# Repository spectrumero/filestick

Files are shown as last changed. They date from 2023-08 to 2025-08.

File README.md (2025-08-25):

# FileStick

This is still a very early work in progress.

This project implements an Econet fileserver "onna stick". Acorn had
the FileStore, so this is kind of a play on words on the FileStore.
The system is built on a Lattice UltraPlus 5K FPGA, which includes
128kbyte of static RAM on the chip, as well as a number of dual ported
blockrams, which makes it ideal for a small system project.

The prototype board is based on the UPduino 3.1 board.
See: https://tinyvision.ai/products/upduino-v3-1

The version 1 board contains the econet front end, the up5k FPGA,
an SD card slot, flash memory and a USB interface, implemented with
an FTDI USB UART.

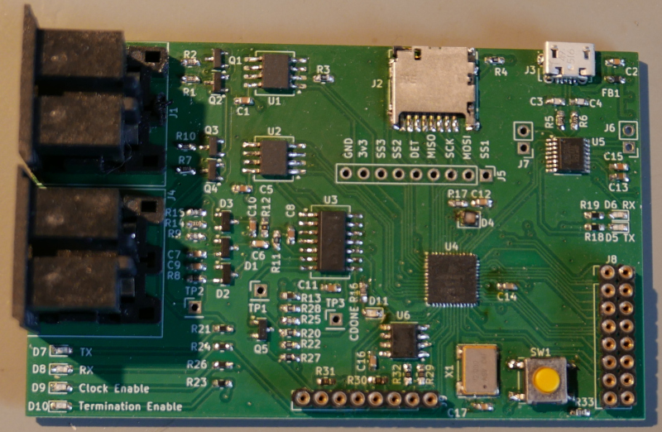
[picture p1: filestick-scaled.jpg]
V1 board


The system consists of a RISC-V core (modified FemtoRV core supporting
some extra CSRs, the ecall instruction to handle system calls, ebreak
and some limited illegal instruction trapping). The core is an rv32imc
(RISC-V 32 bit with the multiply/divide and compressed instructions
extensions).

## Features

* USB powered, < 500mA
* Simple RISC-V implementation and early microcomputer style operating
system. System functions via `ecall` interface.
* Fully buffered econet implementation, with econet exposed via standard
open/read/write/close/ioctl operations.
* Switchable econet clock generation and termination, so that you don't
need a separate clock and terminators for a small Econet.
* Programmable timers.
* USB serial interface with hardware FIFO and hardware CTS/RTS flow control.
Has an interactive mode for use as the system console and raw mode for
transferring files over USB etc.
* FAT support using FatFS for both microSD and built-in flash.
* RGB LED, useful for showing system activity.
* C / C++ programming made easy with newlib and GCC riscv cross compiler,
and a lightweight library and specs file for system-specifics.

## Project structure

* hardware: Contains the Verilog source code. Requires a recent version
of yosys, nextpnr, and the icestorm tools. (Debian users will need to
build these from source, as Debian is still on the old arachnepnr).

* system: Contains the operating system. This isn't a multiuser/
multitasking operating system, it's an OS in the vein of a classic
home micro's operating system. It does provide a number of system
calls using the Linux rv32 syscall numbers. Remember there is no
virtual memory on this very small system, however, some simple memory
protection is planned so that user programs can't accidentally
overwrite kernel memory or device address space.

* lib: The filestick library. This is required for most userspace programs
as at the very least it provides the sbrk implementation needed to properly
support libc's malloc.

## Toolchain

The xPack GNU RISC-V embedded GCC project is used to build all source
code. xPack provides ready-to-run toolchains for many platforms including
Linux, Windows and MacOS. Other GCC toolchains will probably work, but xPack
is likely the easiest/most convenient to use.

The xPack toolchain includes newlib (the libc).

See their releases here: 
https://github.com/xpack-dev-tools/riscv-none-elf-gcc-xpack/releases

The build system uses cmake. If you're running Linux, your distro almost
certainly has cmake. Otherwise see: https://cmake.org/

## Building

To build the gateware, you will need yosys, nextpnr and icestorm tools installed.
Run:

```
$ cd rtl
$ make PCF=<pcf version of your board>
```

If the PCF variable is left unset, the default will be picked which will be for the
latest version of the hardware.

To build the software, assuming a suitable rv32 compiler (e.g. the xpack one suggested):

```
$ cmake -B build
$ cd build
$ make
```

Outputs will be `build/system/filestick-system.bin`, `build/boot/filestick-boot.bin`,
`build/lib/libfilestick.a`, `build/init/init.elf`.

## Installing

To install the gateware, in the `rtl` directory run `make flash` which will use a
suitable FTDI FT232H programmer to write the flash. This also installs the bootloader
as part of the gateware file.

To install the system image with the FTDI programmer:

```
iceprog -d i:0x0403:0x6014 -X -o 0x020000 build/system/filestick-system.bin
```

To install init with the FTDI programmer:

```
iceprog -d i:0x0403:0x6014 -o 0x030000 build/init/init.elf
```

To install the in-built filesystem:

```
iceprog -d i:0x0403:0x6014 -o 0x040000 256kfs.img
```

(256kfs.img is a blank 256k fat12 filesystem, used for storing system settings
and some basic software).

## TODO

There's much to do. More to come later, including how to write programs
for the FileStick.

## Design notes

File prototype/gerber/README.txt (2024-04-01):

Stackup information:

filestick-prototype-Edge_Cuts.gbr - board edge cuts

filestick-prototype-F_Silkscreen.gbr - front silk screen
filestick-prototype-F_Mask.gbr    - front solder mask
filestick-prototype-F_Cu.gbr      - front copper
filestick-prototype-Pwr_Cu.gbr    - layer 2 copper
filestick-prototype-GND_Cu.gbr    - layer 3 copper
filestick-prototype-B_Cu.gbr      - bottom copper
filestick-prototype-B_Mask.gbr    - bottom solder mask

filestick-prototype-PTH.drl       - plated through hole drill file

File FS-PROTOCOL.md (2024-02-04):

# Econet NFS wire protocol

This describes the econet wire protocol for network filesystem operations.
Most of the information was derived from the MDFS manual chapter 10
and verifying the wire level protocol using wireshark between an emulated
BBC Master and the aund fileserver daemon, and checking the emulated
econet payloads.

Unless otherwise indicated, the data payloads all form part of a standard
4-way Econet handshake (scout, ack, data, data ack) sequence. This
document only concerns itself with the data payload.

## Ports

All fileserver commands are sent on port 0x90

Replies are expected to be on port 0x99

## Standard things with every data packet

A typical NetFS packet looks like this:

```
Bytes: 
0,1         Destination station and net
2,3         Source station and net
4           Reply port
5           Function code
6           User root dir context handle
7           Current directory context handle
8           Current library context handle
9...        Payload
```

The context handles are all set to 0x00 if a station hasn't yet
logged on, e.g. the first `*I AM` command will be sent with
bytes 6,7,8 set to 0x00.

## Typical NetFS logon sequence

Client station sends a machine peek to the fileserver:

```
FE 00       Dst: Station 254, net 0
19 00       Src: Station 25, net 0
88          Control byte - Machine peek
00          Port 0x00 (Immediate)
00 DB 00 00 Payload (ignored?)
```

Reply is as follows:
```
19 00       Dst: Station 25, net 0
FE 00       Src: Station 254, net 0
40 66 07 01 Payload: Type 0x40, Manufacturer 0x66, version 1.7
```

Then the `I AM` command is sent, with the handles all set to 0.
The data is sent to port 0x99 on the fileserver with the
normal 4-way Econet handshake. The data packet is as follows:

```
FE 00       Dst: Stn 254, net 0
19 00       Src: Stn 25, net 0
90          Reply port 0x90
00          Function code 0 (command line)
00          User root dir context handle set to 0
00          Current directory context handle set to 0
00          Current library context handle set to 0
49 20 41 4d 20 53 48 41 44 45 53 0d
            Payload (I AM SHADES\n)
```

In the case a password is supplied, the password is supplied
in plain text after the `I AM` command, e.g. if the password
is FOO BAR BAZ, the payload will be `I AM SHADES FOO BAR BAZ\n`.
Note that all this is in the clear, so don't use passwords
you care about for other things...

Curiously, if the command on the client is written as
`*I AM SHADES :` (so the password isn't echoed) the payload
is terminated by `0x0D 0x00` instead of just `0x0D`.

The fileserver replies on port 0x90 using the normal 4-way
Econet handshake. The data packet is as follows:

```
19 00       Dst: Station 25, net 0
FE 00       Src: Station 254, net 0
05          Command code 05, I AM
00          Result code
03          URD handle
05          CSD handle
06          LIB handle
00          Boot option (lowest 4 bits only)
```

The URD, CSD, LIB handles are then used with all subsequent
NetFS commands.

If the `I AM` command fails, the reply from the fileserver
will look like this:

```
19 00       Dst: Station 25, net 0
FE 00       Src: Station 254, net 0
00          Command code 00, No action, command complete
BB          FS error 0xBB, incorrect password
String      String "Incorrect password\n"
```

## Function code 0x00 (Command line, including `*I AM`)

Payload is simply the command line terminated by a newline
character (0x0d) and without the `*`. For instance,
`*I AM SHADES` is sent as `49 20 41 4d 20 53 48 41 44 45 53 0d`

Example:
```
FE 00       Dst: Stn 254, net 0
19 00       Src: Stn 25, net 0
90          Reply port 0x90
00          Function code 0 (command line)
rh          User root dir context handle
dh          Current directory context handle
lh          Current library context handle
String      Command line terminated by 0x0D
```

## Function code 0x12, Read object information

The general form of this command is an argument code after the
standard NetFS data, followed by an object name terminated by
a CR (0x0D). The following arguments exist:

* 1         Object creation date
* 2         Load and execute address
* 3         Object extent (3 bytes only)
* 4         Access byte (as for EXAMINE)
* 5         All object attributes
* 6         Access and cycle number of directory
* 64        Read creation and update date

The reply for arg 1-5 is:

For arg 6:

```
00          Undefined
00          Always zero
0A          ?
String[10]  Directory name padded by spaces
Access      Access to dir, 0x00 - owner, 0xFF - public
cc          Cycle number
```

### Arg=6, Access and cycle number of dir

Note that the directory name is just sent as-is, so
a bare name is relative, but you may have `$.` (root)
or anything else in there.

Example: `*. LIBRARY` is run on the client.

```
FE 00       Dst: Stn 254, net 0
19 00       Src: Stn 25, net 0
90          Reply port 0x90
12          Function code 12 (read object info)
rh          User root dir context handle
dh          Current directory context handle
lh          Current library context handle
06          Argument code
String      Directory name terminated with \n
```

Reply:
```
19 00       Dst: Stn 25, net 0
FE 00       Src: Stn 254, net 0
00          undefined
00          always 0
0A          always 0x0A ?
String[10]  Library   \n
00          Owner access
00          Cycle number
```

## Execution of various commands

Many operations consist of multiple different file server commands sent
in a sequence. Listed is a summary of the sequence of operations for common
commands run on the client.

### `*CAT` directory listing

* Client sends 0x12 (Read object information) with argument=6 (Access and cycle of dir)
* Server responds with dir name, access and cycle
* Client sends 0x15 (Read user environment)
* Server responds with disc name, CSD and LIB (all padded with spaces)

For as many times as is required to get entire listing:
* Client sends 0x03 (Examine) on named directory with arg=3 (Object names and formats)
* Server responds with directory listing in arg=3 format

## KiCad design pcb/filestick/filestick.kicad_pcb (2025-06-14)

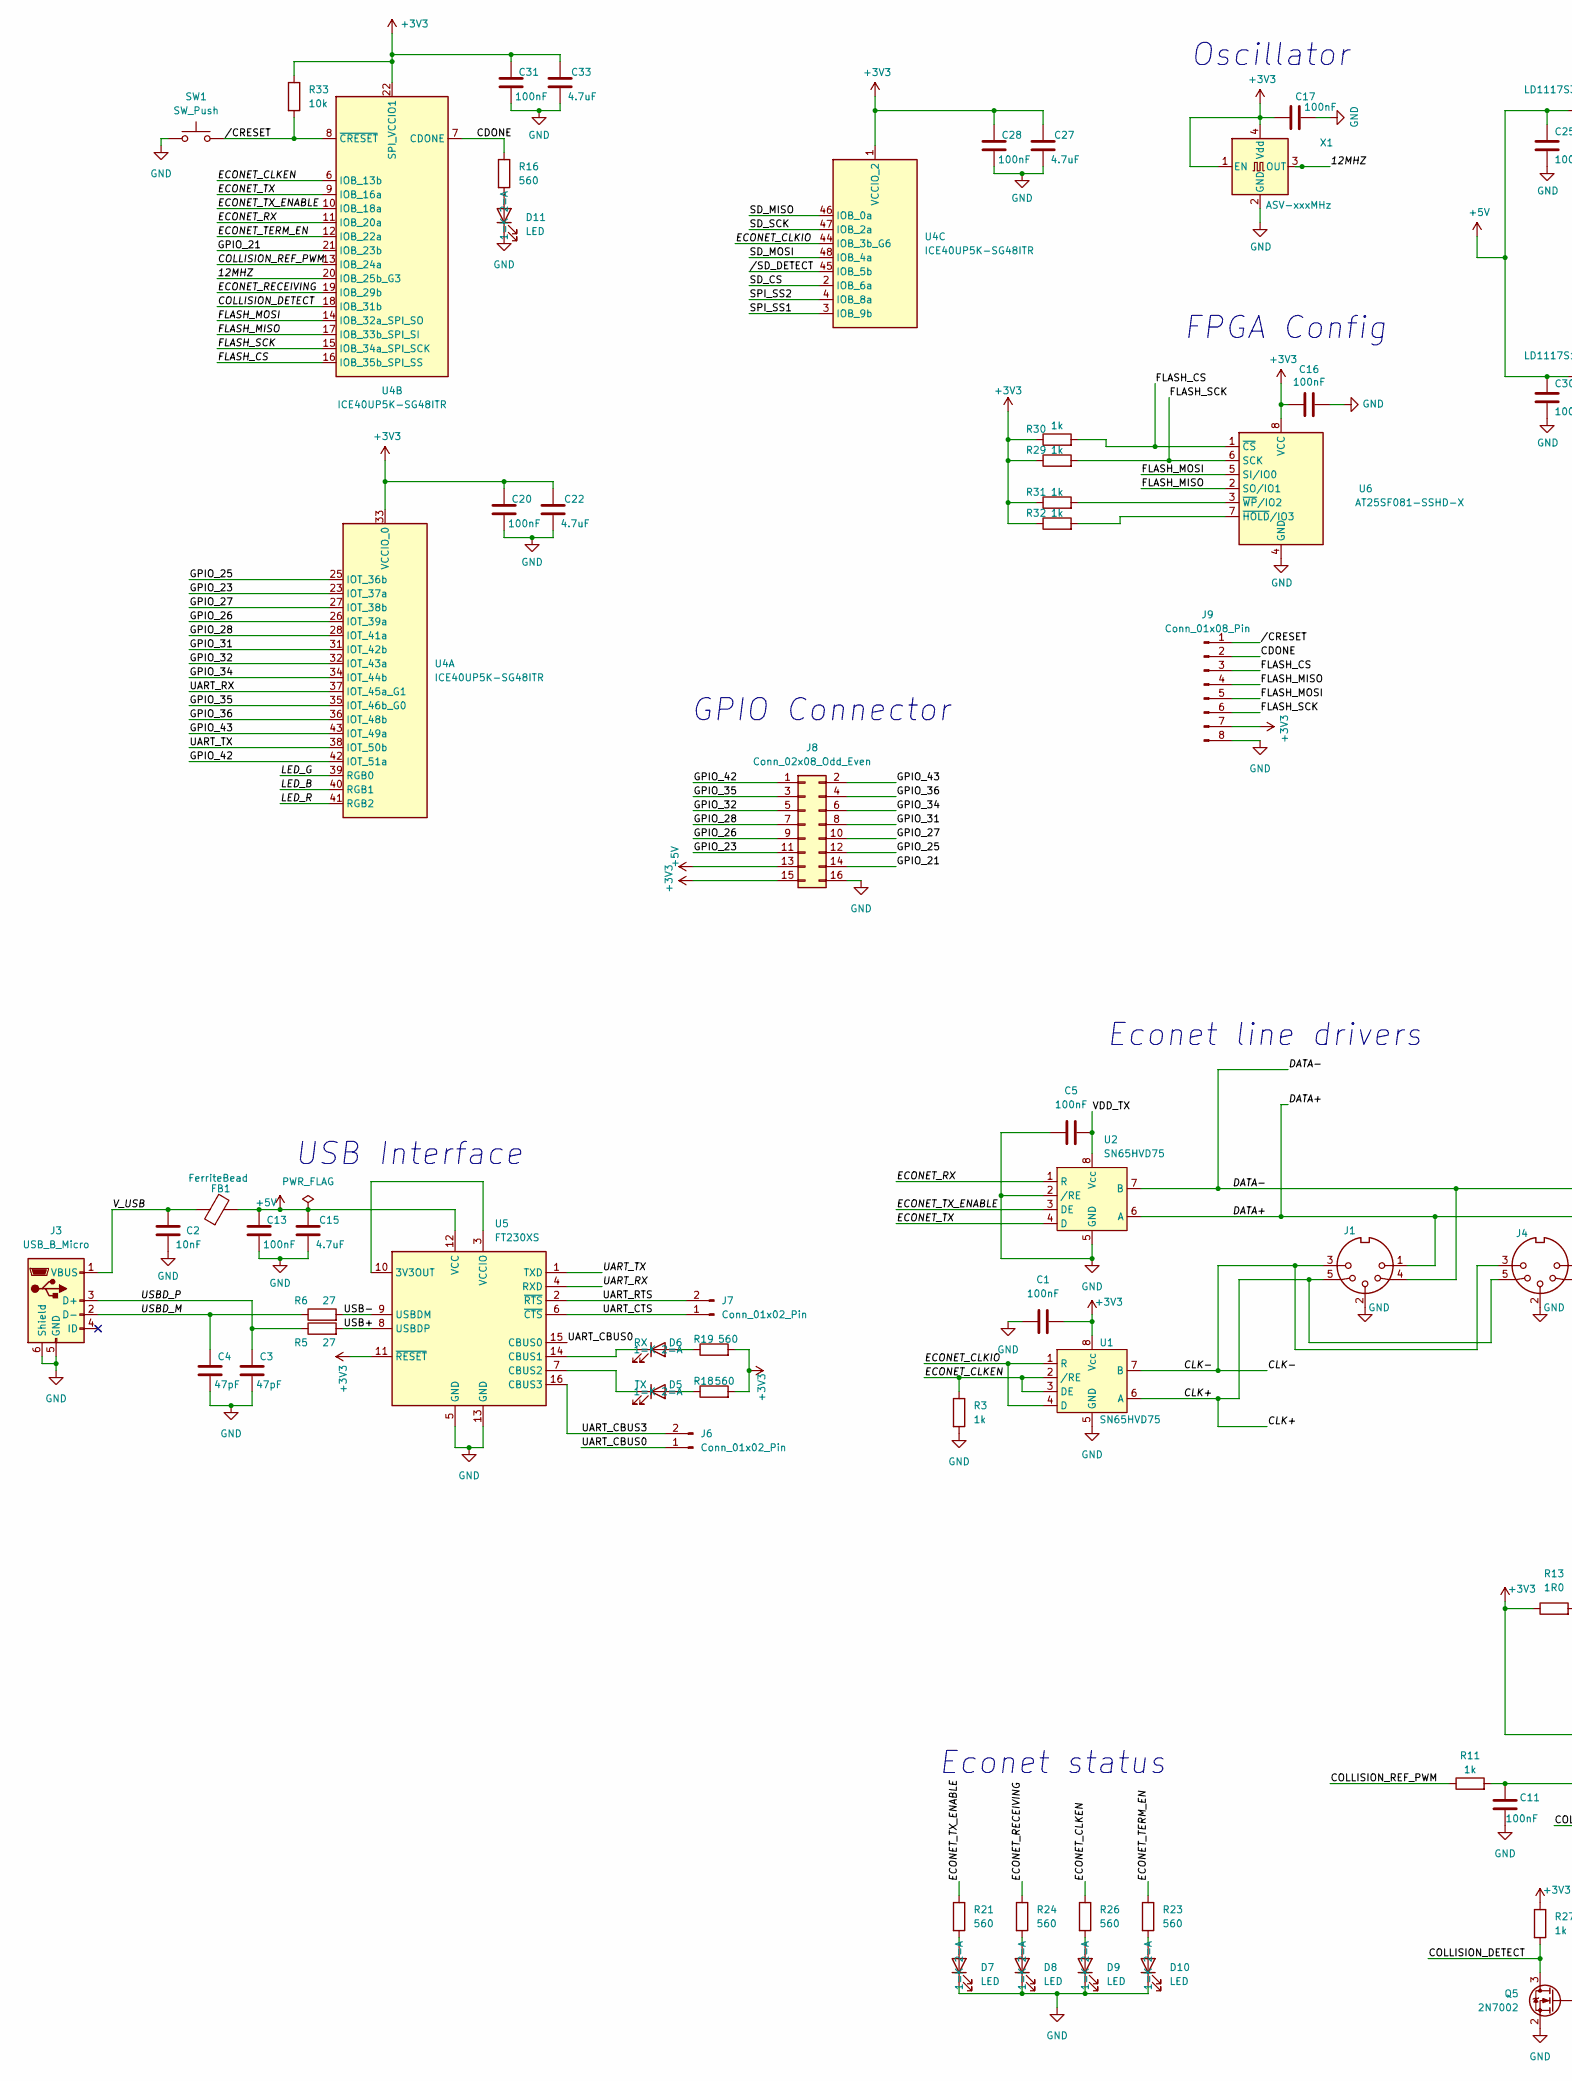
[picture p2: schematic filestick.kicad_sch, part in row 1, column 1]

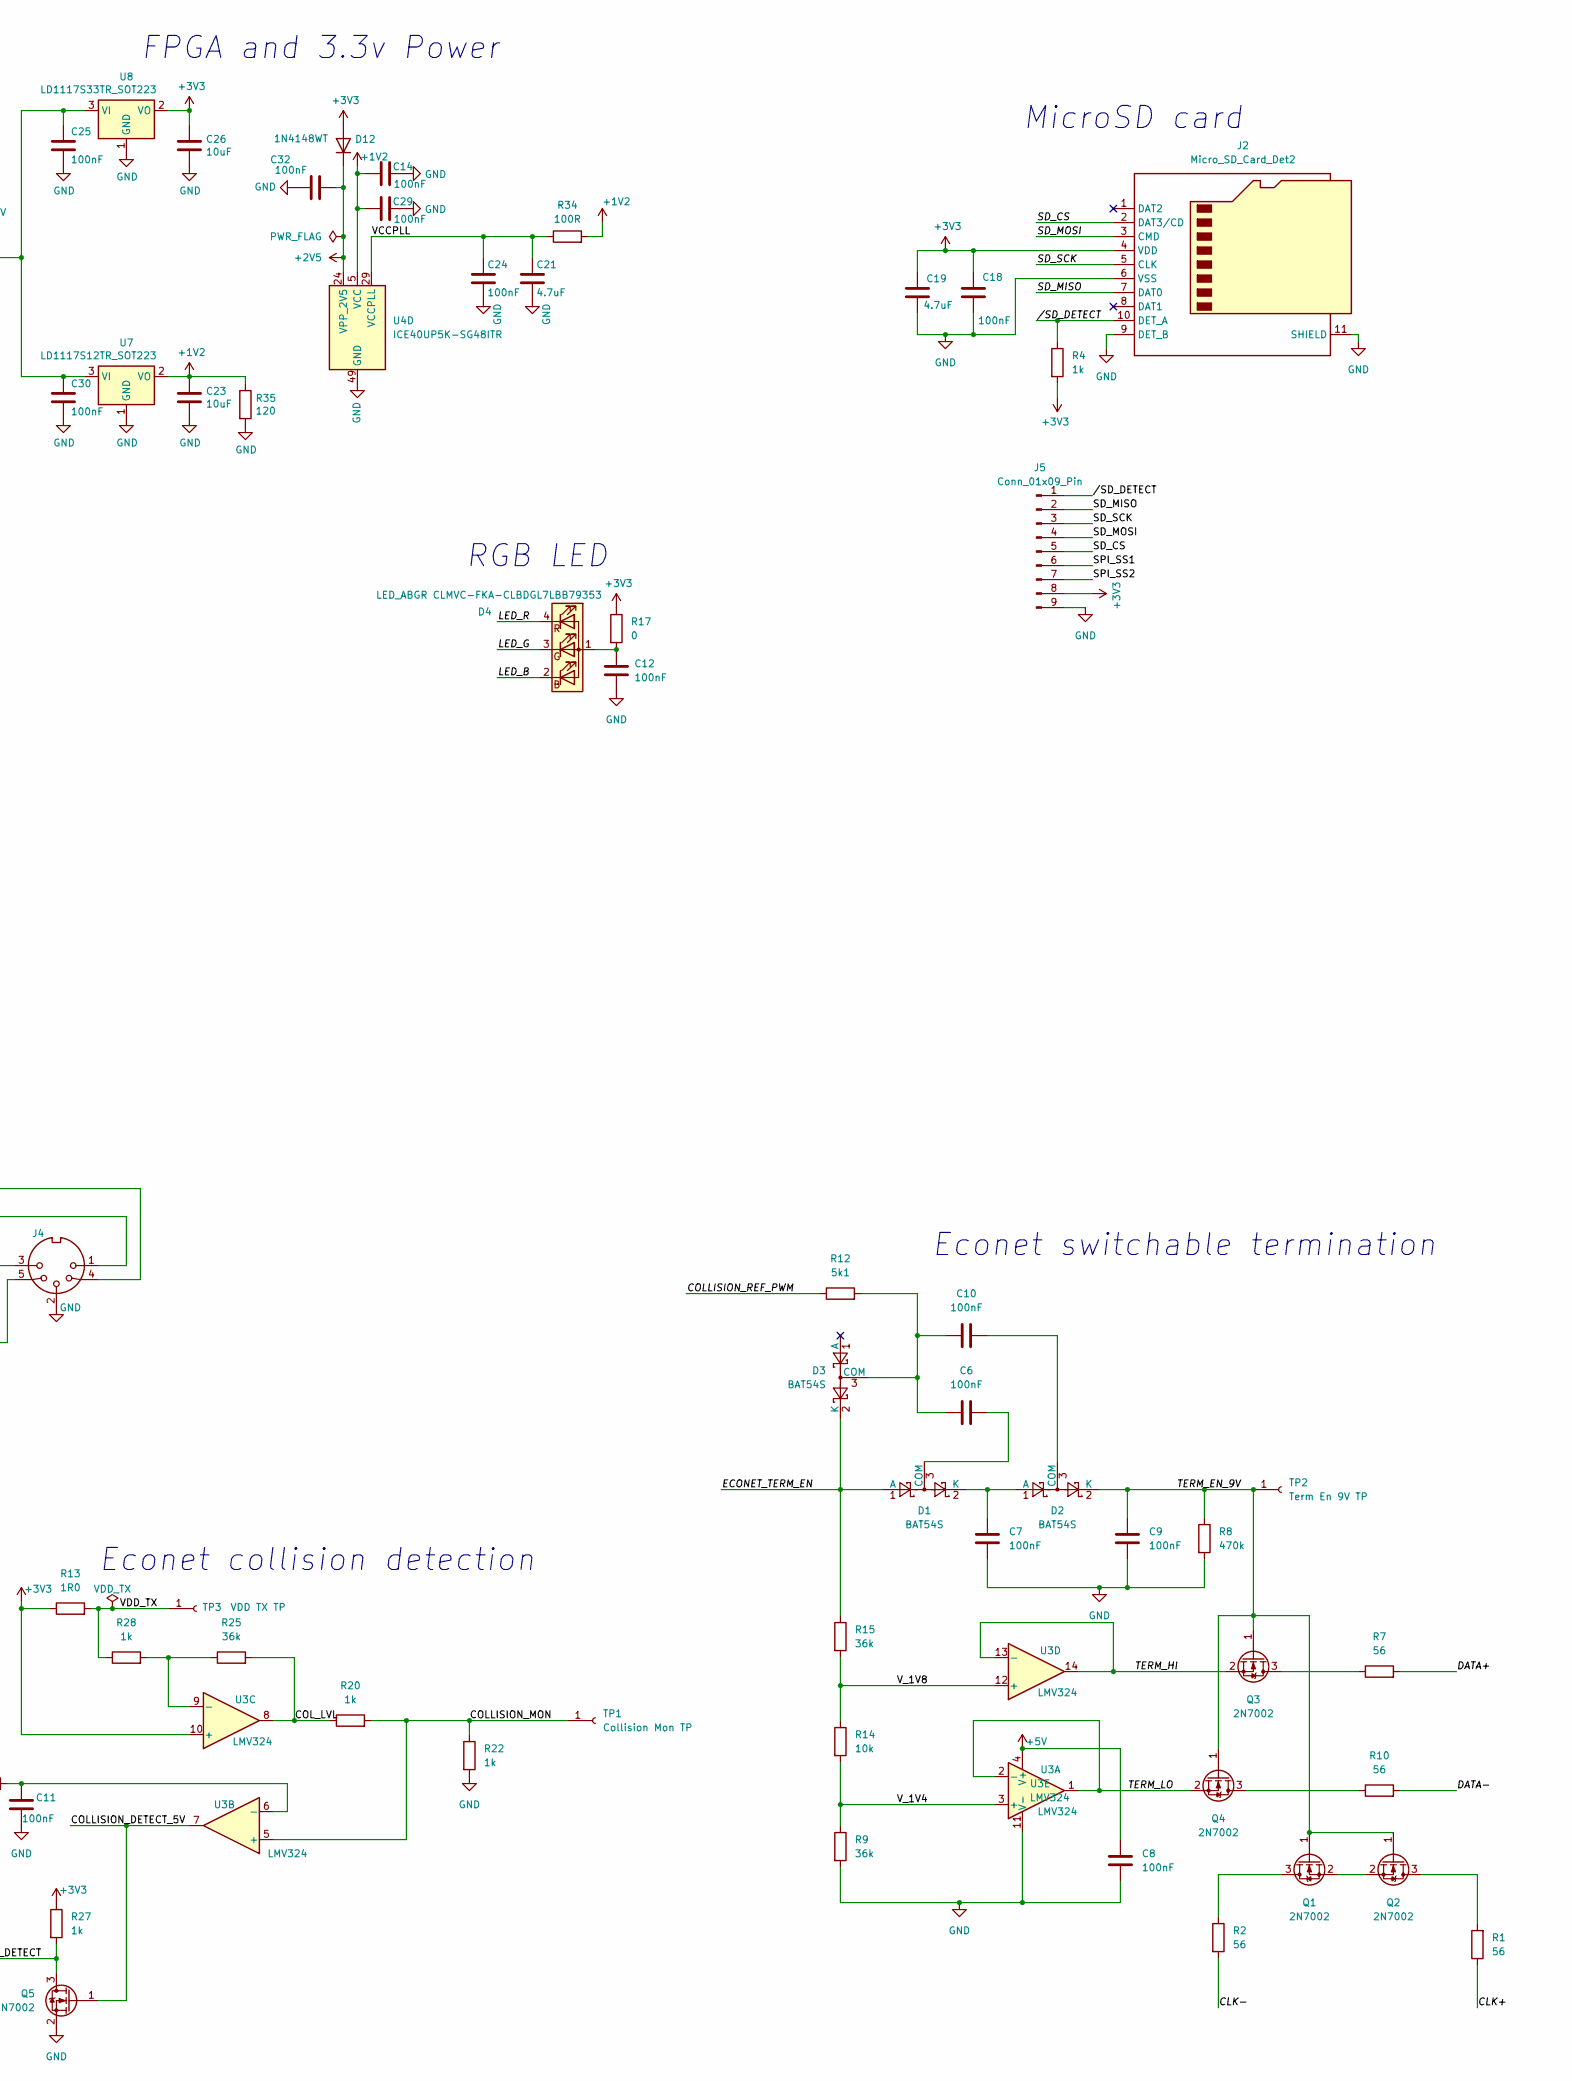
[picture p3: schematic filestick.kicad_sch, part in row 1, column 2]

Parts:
C1, C5, C6, C7, C8, C9, C10, C11, C12, C13, C14, C16, C17, C18, C20, C24, C25, C28, C29, C30, C31, C32: 100nF; C_0603_1608Metric_Pad1.08x0.95mm_HandSolder
C2: 10nF; C_0603_1608Metric_Pad1.08x0.95mm_HandSolder
C3, C4: 47pF; C_0603_1608Metric_Pad1.08x0.95mm_HandSolder
C15, C19, C21, C22, C27, C33: 4.7uF; C_0603_1608Metric_Pad1.08x0.95mm_HandSolder
C23, C26: 10uF; C_0603_1608Metric_Pad1.08x0.95mm_HandSolder
D1, D2, D3: BAT54S; SOT-23
D4: LED_ABGR CLMVC-FKA-CLBDGL7LBB79353; LED_Cree-PLCC4_2x2mm_CW
D5: TX; LED_0603_1608Metric_Pad1.05x0.95mm_HandSolder
D6: RX; LED_0603_1608Metric_Pad1.05x0.95mm_HandSolder
D7, D8, D9, D10, D11: LED; LED_0603_1608Metric_Pad1.05x0.95mm_HandSolder
D12: 1N4148WT; D_SOD-523
FB1: FerriteBead; L_0603_1608Metric_Pad1.05x0.95mm_HandSolder
J1, J4: DIN-5_180degree; Lumberg_DIN41524_5pin
J2: Micro_SD_Card_Det2; microSD_HC_Hirose_DM3D-SF
J3: USB_B_Micro; USB_Micro-B_Molex-105017-0001
J5: Conn_01x09_Pin; PinHeader_1x09_P2.54mm_Vertical
J6, J7: Conn_01x02_Pin; PinHeader_1x02_P2.54mm_Vertical
J8: Conn_02x08_Odd_Even; PinHeader_2x08_P2.54mm_Vertical
J9: Conn_01x08_Pin; PinHeader_1x08_P2.54mm_Vertical
Q1, Q2, Q3, Q4, Q5: 2N7002; SOT-23
R1, R2, R7, R10: 56; R_0603_1608Metric_Pad0.98x0.95mm_HandSolder
R3, R4, R11, R20, R22, R27, R28, R29, R30, R31, R32: 1k; R_0603_1608Metric_Pad0.98x0.95mm_HandSolder
R5, R6: 27; R_0603_1608Metric_Pad0.98x0.95mm_HandSolder
R8: 470k; R_0603_1608Metric_Pad0.98x0.95mm_HandSolder
R9, R15, R25: 36k; R_0603_1608Metric_Pad0.98x0.95mm_HandSolder
R12: 5k1; R_0603_1608Metric_Pad0.98x0.95mm_HandSolder
R13: 1R0; R_0603_1608Metric_Pad0.98x0.95mm_HandSolder
R14, R33: 10k; R_0603_1608Metric_Pad0.98x0.95mm_HandSolder
R16, R18, R19, R21, R23, R24, R26: 560; R_0603_1608Metric_Pad0.98x0.95mm_HandSolder
R17: 0; R_0603_1608Metric_Pad0.98x0.95mm_HandSolder
R34: 100R; R_0603_1608Metric_Pad0.98x0.95mm_HandSolder
R35: 120; R_0603_1608Metric_Pad0.98x0.95mm_HandSolder
SW1: SW_Push; SW_SPST_PTS645
TP1: Collision Mon TP; PinHeader_1x01_P2.54mm_Vertical
TP2: Term En 9V TP; PinHeader_1x01_P2.54mm_Vertical
TP3: VDD TX TP; PinHeader_1x01_P2.54mm_Vertical
U1, U2: SN65HVD75; SOIC-8_5.3x6.2mm_P1.27mm
U3: LMV324; SO-14_5.3x10.2mm_P1.27mm
U4: ICE40UP5K-SG48ITR; QFN-48-1EP_7x7mm_P0.5mm_EP5.6x5.6mm
U5: FT230XS; SSOP-16_3.9x4.9mm_P0.635mm
U6: AT25SF081-SSHD-X; SOIC-8_3.9x4.9mm_P1.27mm
U7: LD1117S12TR_SOT223; SOT-223-3_TabPin2
U8: LD1117S33TR_SOT223; SOT-223-3_TabPin2
X1: ASV-xxxMHz; Oscillator_SMD_Abracon_ASV-4Pin_7.0x5.1mm

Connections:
+1V2: C14.2, C23.1, C29.2, R34.2, R35.1, U4.5 (VCC), U4.30 (VCC), U7.2 (VO)
+2V5: C32.1, D12.1 (K), U4.24 (VPP_2V5)
+3V3: C1.1, C16.1, C17.1, C18.1, C19.1, C20.2, C22.2, C26.1, C27.2, C28.2, C31.2, C33.2, D12.2 (A), J2.4 (VDD), J5.8, J8.15, J9.7, R4.2, R13.1, R17.1, R18.2, R19.2, R27.1, R29.1, R30.1, R31.1, R32.1, R33.1, U1.8 (Vcc), U3.10 (+), U4.1 (VCCIO_2), U4.22 (SPI_VCCIO1), U4.33 (VCCIO_0), U5.11 (~RESET), U6.8 (VCC), U8.2 (VO), X1.1 (EN), X1.4 (Vdd)
+5V: C8.1, C13.2, C15.2, C25.1, C30.1, FB1.2, J8.13, U3.4 (V+), U5.12 (VCC), U7.3 (VI), U8.3 (VI)
/12MHZ: U4.20 (IOB_25b_G3), X1.3 (OUT)
/CDONE: J9.2, R16.1, U4.7 (CDONE)
/CLK+: J1.5, J4.5, R1.1, U1.6 (A)
/CLK-: J1.3, J4.3, R2.2, U1.7 (B)
/COLLISION_DETECT: Q5.3 (D), R27.2, U4.18 (IOB_31b)
/COLLISION_DETECT_5V: Q5.1 (G), U3.7
/COLLISION_MON: R20.2, R22.1, TP1.1, U3.5 (+)
/COLLISION_REF_PWM: R11.1, R12.1, U4.13 (IOB_24a)
/COL_LVL: R20.1, R25.2, U3.8
/DATA+: J1.1, J4.1, R7.2, U2.6 (A)
/DATA-: J1.4, J4.4, R10.2, U2.7 (B)
/ECONET_CLKEN: R3.1, R26.1, U1.2 (/RE), U1.3 (DE), U4.6 (IOB_13b)
/ECONET_CLKIO: U1.1 (R), U1.4 (D), U4.44 (IOB_3b_G6)
/ECONET_RECEIVING: R24.1, U4.19 (IOB_29b)
/ECONET_RX: U2.1 (R), U4.11 (IOB_20a)
/ECONET_TERM_EN: D1.1 (A), D3.2 (K), R15.1, R23.1, U4.12 (IOB_22a)
/ECONET_TX: U2.4 (D), U4.9 (IOB_16a)
/ECONET_TX_ENABLE: R21.1, U2.3 (DE), U4.10 (IOB_18a)
/FLASH_CS: J9.3, R30.2, U4.16 (IOB_35b_SPI_SS), U6.1 (~CS)
/FLASH_MISO: J9.4, U4.17 (IOB_33b_SPI_SI), U6.2 (SO/IO1)
/FLASH_MOSI: J9.5, U4.14 (IOB_32a_SPI_SO), U6.5 (SI/IO0)
/FLASH_SCK: J9.6, R29.2, U4.15 (IOB_34a_SPI_SCK), U6.6 (SCK)
/GPIO_21: J8.14, U4.21 (IOB_23b)
/GPIO_23: J8.11, U4.23 (IOT_37a)
/GPIO_25: J8.12, U4.25 (IOT_36b)
/GPIO_26: J8.9, U4.26 (IOT_39a)
/GPIO_27: J8.10, U4.27 (IOT_38b)
/GPIO_28: J8.7, U4.28 (IOT_41a)
/GPIO_31: J8.8, U4.31 (IOT_42b)
/GPIO_32: J8.5, U4.32 (IOT_43a)
/GPIO_34: J8.6, U4.34 (IOT_44b)
/GPIO_35: J8.3, U4.35 (IOT_46b_G0)
/GPIO_36: J8.4, U4.36 (IOT_48b)
/GPIO_42: J8.1, U4.42 (IOT_51a)
/GPIO_43: J8.2, U4.43 (IOT_49a)
/LED_B: D4.2 (BK), U4.40 (RGB1)
/LED_G: D4.3 (GK), U4.39 (RGB0)
/LED_R: D4.4 (RK), U4.41 (RGB2)
/SD_CS: J2.2 (DAT3/CD), J5.5, U4.2 (IOB_6a)
/SD_MISO: J2.7 (DAT0), J5.2, U4.46 (IOB_0a)
/SD_MOSI: J2.3 (CMD), J5.4, U4.48 (IOB_4a)
/SD_SCK: J2.5 (CLK), J5.3, U4.47 (IOB_2a)
/SPI_SS1: J5.6, U4.3 (IOB_9b)
/SPI_SS2: J5.7, U4.4 (IOB_8a)
/TERM_EN_9V: C9.1, D2.2 (K), Q1.1 (G), Q2.1 (G), Q3.1 (G), Q4.1 (G), R8.1, TP2.1
/TERM_HI: Q3.2 (S), U3.13 (-), U3.14
/TERM_LO: Q4.2 (S), U3.1, U3.2 (-)
/UART_CBUS0: J6.1, U5.15 (CBUS0)
/UART_CBUS3: J6.2, U5.16 (CBUS3)
/UART_CTS: J7.1, U5.6 (~CTS)
/UART_RTS: J7.2, U5.2 (~RTS)
/UART_RX: U4.37 (IOT_45a_G1), U5.4 (RXD)
/UART_TX: U4.38 (IOT_50b), U5.1 (TXD)
/USB+: R5.2, U5.8 (USBDP)
/USB-: R6.2, U5.9 (USBDM)
/USBD_M: C4.1, J3.2 (D-), R6.1
/USBD_P: C3.1, J3.3 (D+), R5.1
/VCCPLL: C21.1, C24.1, R34.1, U4.29 (VCCPLL)
/VDD_TX: C5.2, R13.2, R28.1, TP3.1, U2.8 (Vcc)
/V_1V4: R9.1, R14.2, U3.3 (+)
/V_1V8: R14.1, R15.2, U3.12 (+)
/V_USB: C2.1, FB1.1, J3.1 (VBUS)
//CRESET: J9.1, R33.2, SW1.2, U4.8 (~CRESET)
//SD_DETECT: J2.10 (DET_A), J5.1, R4.1, U4.45 (IOB_5b)
GND: C1.2, C2.2, C3.2, C4.2, C5.1, C7.2, C8.2, C9.2, C11.2, C12.2, C13.1, C14.1, C15.1, C16.2, C17.2, C18.2, C19.2, C20.1, C21.2, C22.1, C23.2, C24.2, C25.2, C26.2, C27.1, C28.1, C29.1, C30.2, C31.1, C32.2, C33.1, D7.1 (K), D8.1 (K), D9.1 (K), D10.1 (K), D11.1 (K), J1.2, J2.6 (VSS), J2.9 (DET_B), J2.11 (SHIELD), J3.5 (GND), J3.6 (Shield), J4.2, J5.9, J8.16, J9.8, Q5.2 (S), R3.2, R8.2, R9.2, R22.2, R35.2, SW1.1, U1.5 (GND), U2.2 (/RE), U2.5 (GND), U3.11 (V-), U4.49 (GND), U5.5 (GND), U5.13 (GND), U6.4 (GND), U7.1 (GND), U8.1 (GND), X1.2 (GND)
unnamed: C6.2, D1.3 (COM)
unnamed: C7.1, D1.2 (K), D2.1 (A)
unnamed: C10.2, D2.3 (COM)
unnamed: C6.1, C10.1, D3.3 (COM), R12.2
unnamed: C12.1, D4.1 (A), R17.2
unnamed: D5.2 (A), R18.1
unnamed: D5.1 (K), U5.7 (CBUS2)
unnamed: D6.2 (A), R19.1
unnamed: D6.1 (K), U5.14 (CBUS1)
unnamed: D7.2 (A), R21.2
unnamed: D8.2 (A), R24.2
unnamed: D9.2 (A), R26.2
unnamed: D10.2 (A), R23.2
unnamed: D11.2 (A), R16.2
unnamed: Q1.3 (D), R2.1
unnamed: Q1.2 (S), Q2.2 (S)
unnamed: Q2.3 (D), R1.2
unnamed: Q3.3 (D), R7.1
unnamed: Q4.3 (D), R10.1
unnamed: C11.1, R11.2, U3.6 (-)
unnamed: R25.1, R28.2, U3.9 (-)
unnamed: U5.3 (VCCIO), U5.10 (3V3OUT)
unnamed: R32.2, U6.7 (~HOLD/IO3)
unnamed: R31.2, U6.3 (~WP/IO2)

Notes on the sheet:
GPIO Connector
MicroSD card
Econet switchable termination
RGB LED
FPGA and 3.3v Power
Econet status
Econet line drivers
Oscillator
FPGA Config
USB Interface
Econet collision detection

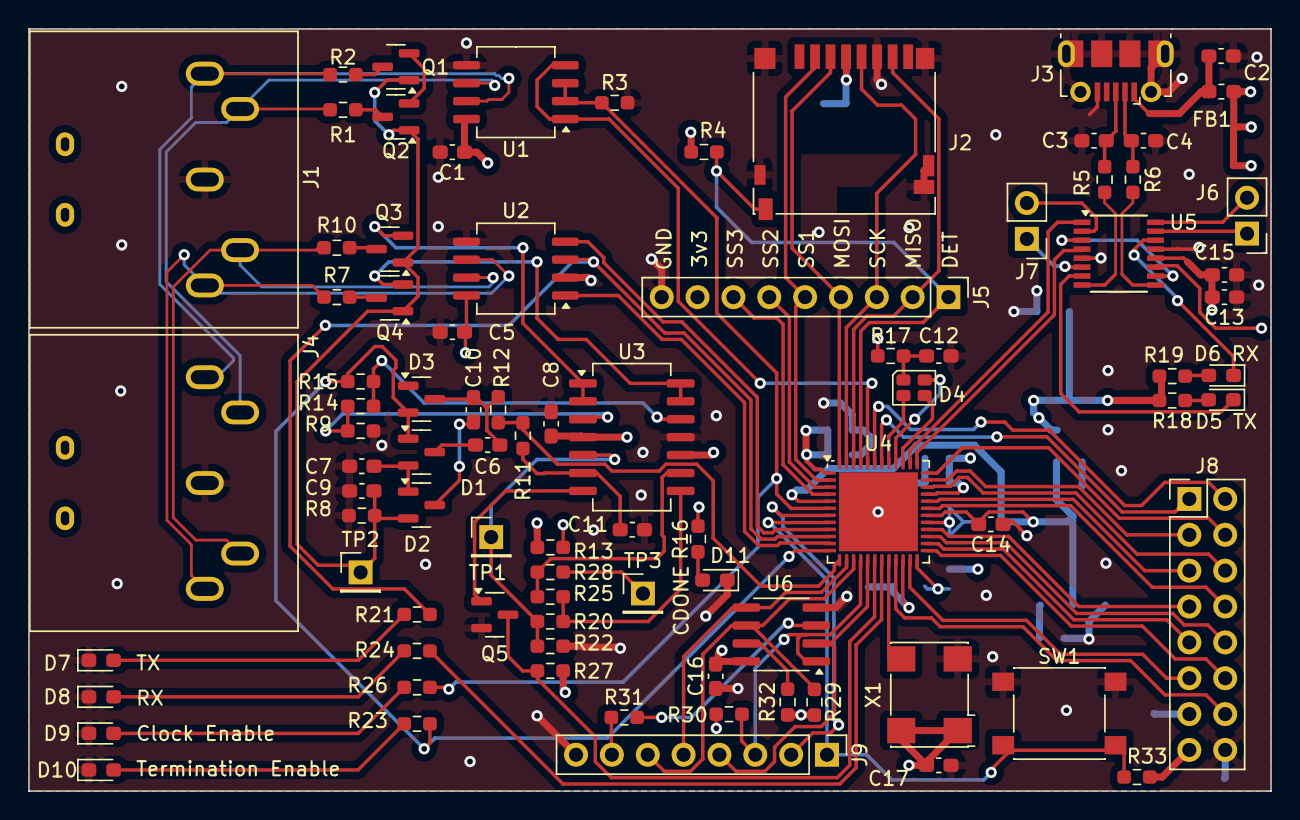
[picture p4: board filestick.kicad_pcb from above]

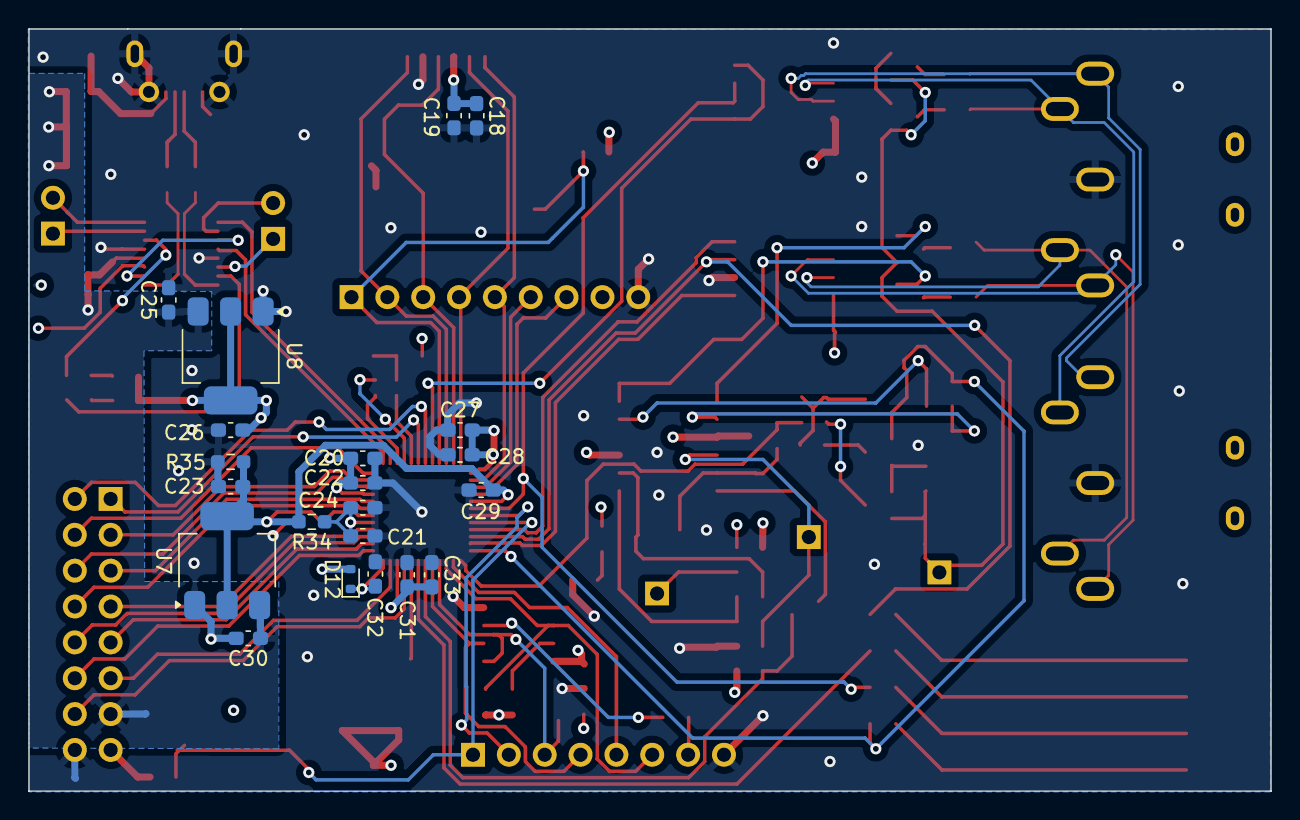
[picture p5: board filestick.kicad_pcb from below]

Board: 4 copper layers, 88.0 x 54.0 mm, 108 parts (21 on the bottom side), 93 nets.

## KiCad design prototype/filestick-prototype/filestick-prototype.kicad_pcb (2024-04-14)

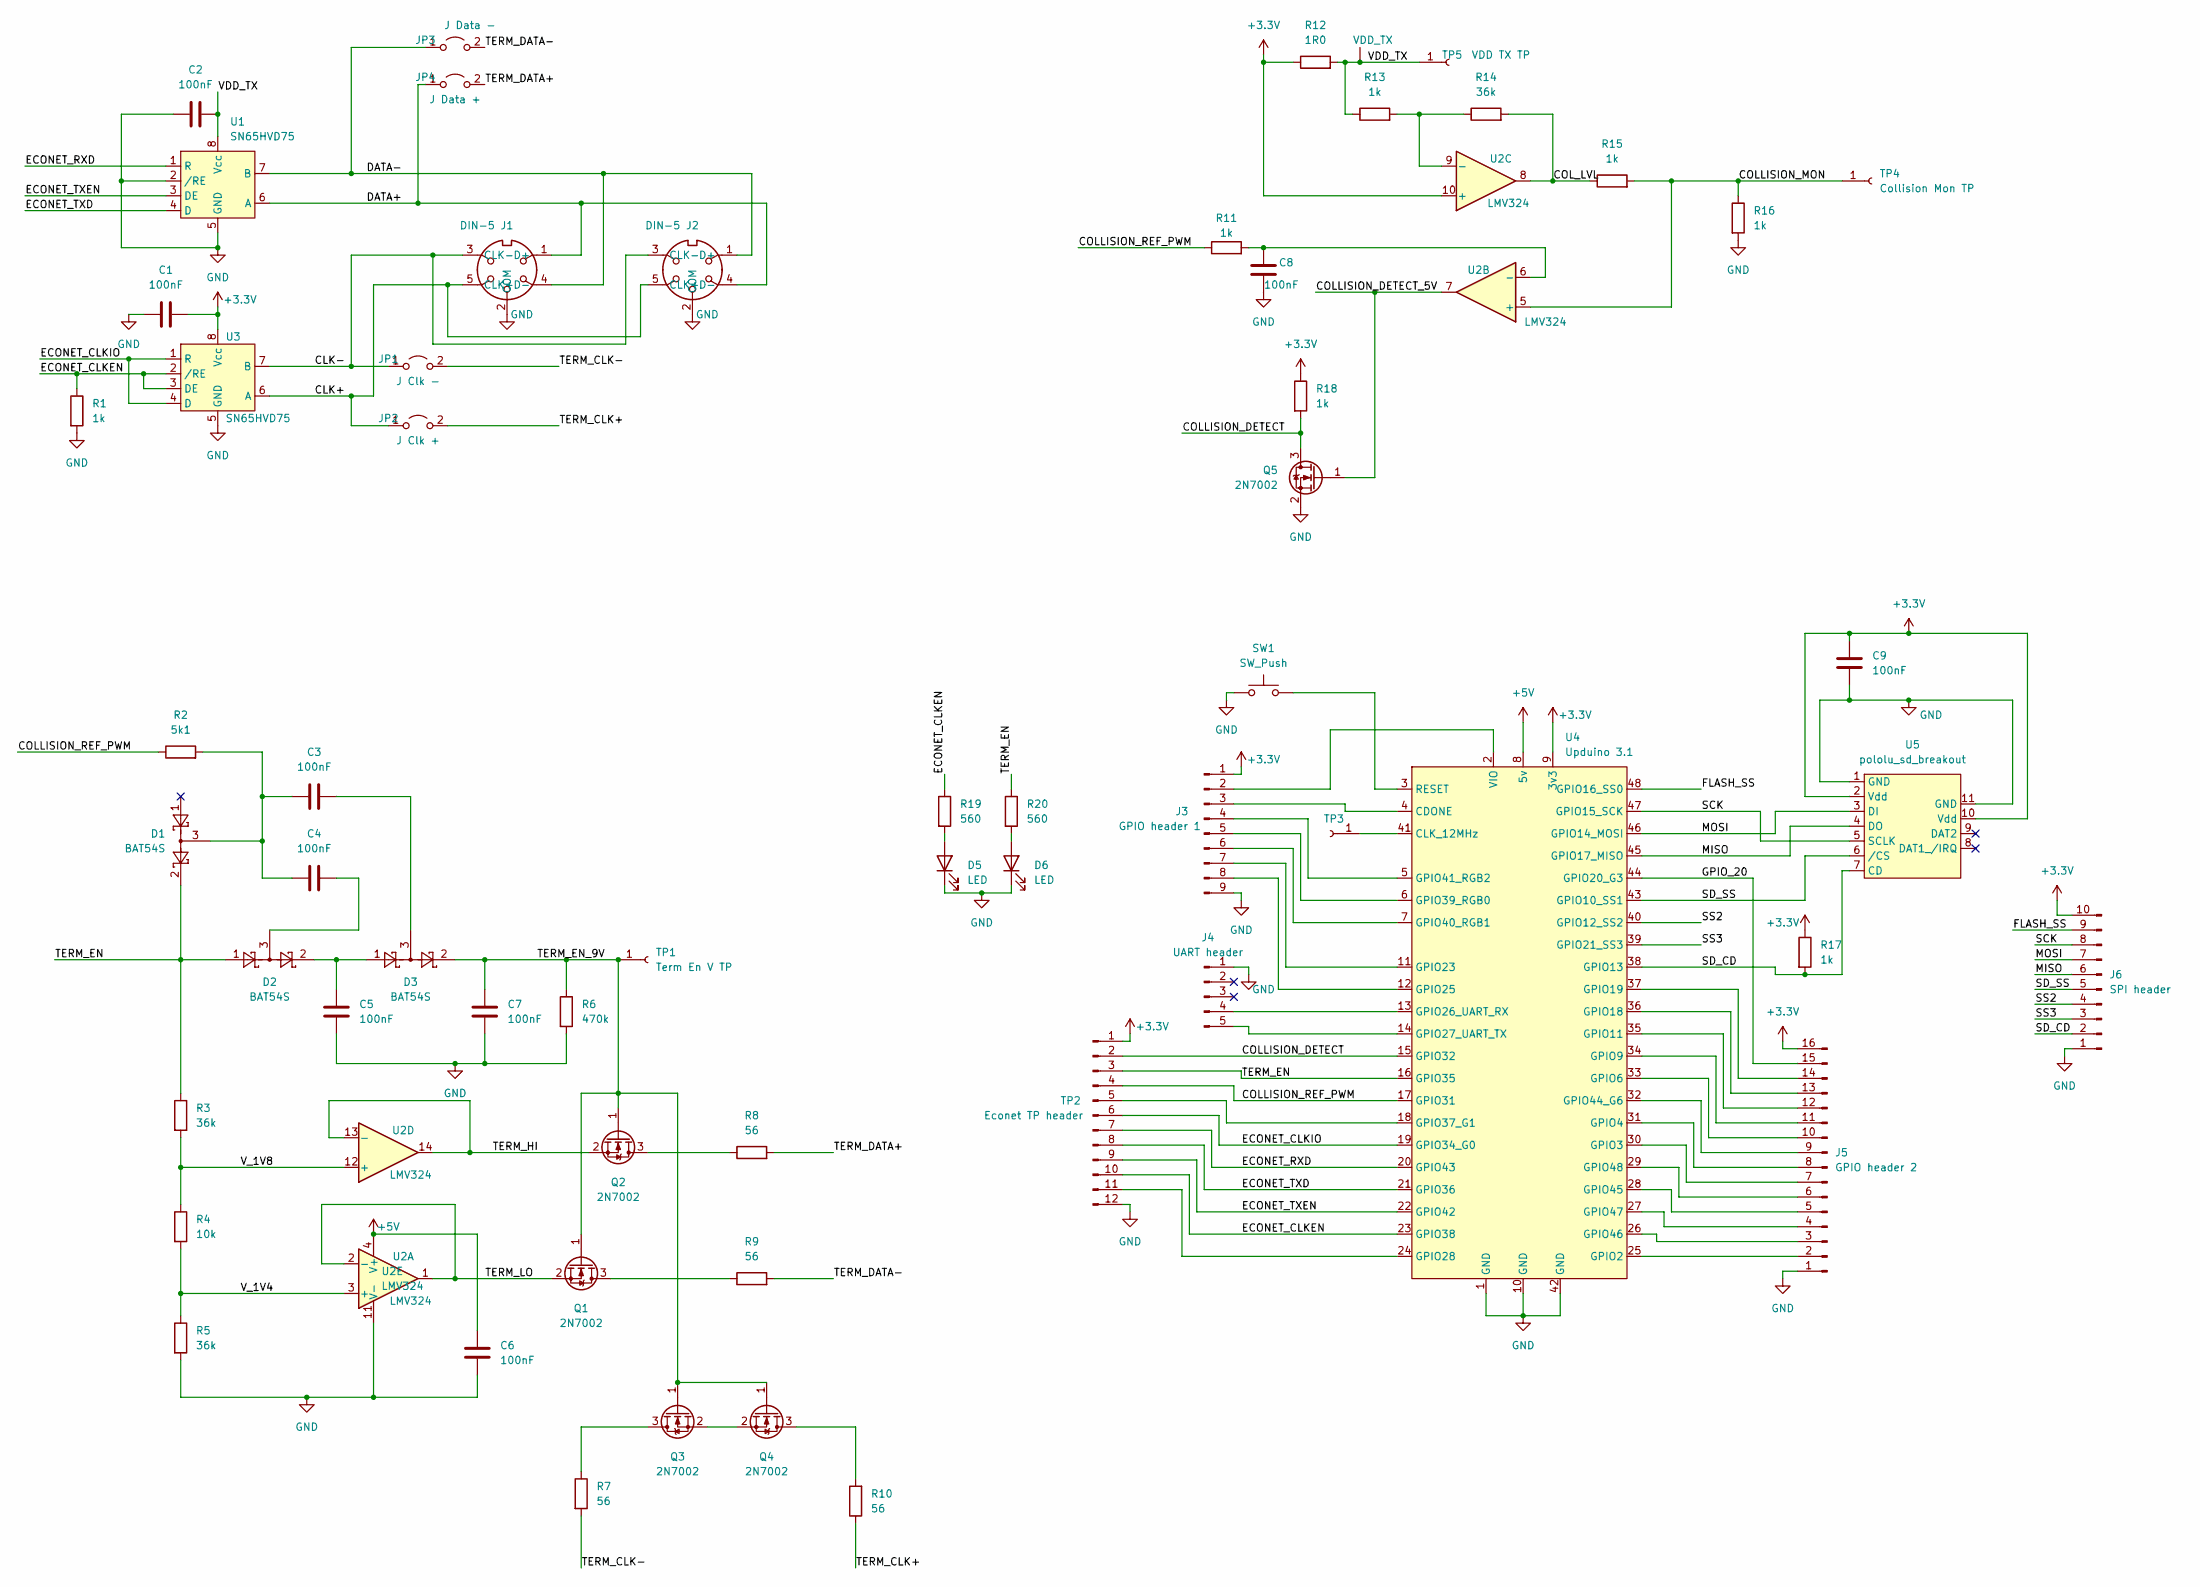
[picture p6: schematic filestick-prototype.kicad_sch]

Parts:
C1, C2, C3, C4, C5, C6, C7, C8, C9: 100nF; C_0603_1608Metric_Pad1.08x0.95mm_HandSolder
D1, D2, D3: BAT54S; SOT-23
D5, D6: LED; LED_0603_1608Metric_Pad1.05x0.95mm_HandSolder
J1, J2: DIN-5; Lumberg_DIN41524_5pin
J3: GPIO header 1; PinHeader_1x09_P2.54mm_Vertical
J4: UART header; PinHeader_1x05_P2.54mm_Vertical
J5: GPIO header 2; PinHeader_1x16_P2.54mm_Vertical
J6: SPI header; PinHeader_1x10_P2.54mm_Vertical
JP1: J Clk -; PinHeader_1x02_P2.54mm_Vertical
JP2: J Clk +; PinHeader_1x02_P2.54mm_Vertical
JP3: J Data -; PinHeader_1x02_P2.54mm_Vertical
JP4: J Data +; PinHeader_1x02_P2.54mm_Vertical
Q1, Q2, Q3, Q4, Q5: 2N7002; SOT-23
R1, R11, R13, R15, R16, R17, R18: 1k; R_0603_1608Metric_Pad0.98x0.95mm_HandSolder
R2: 5k1; R_0603_1608Metric_Pad0.98x0.95mm_HandSolder
R3, R5, R14: 36k; R_0603_1608Metric_Pad0.98x0.95mm_HandSolder
R4: 10k; R_0603_1608Metric_Pad0.98x0.95mm_HandSolder
R6: 470k; R_0603_1608Metric_Pad0.98x0.95mm_HandSolder
R7, R8, R9, R10: 56; R_0603_1608Metric_Pad0.98x0.95mm_HandSolder
R12: 1R0; R_0603_1608Metric_Pad0.98x0.95mm_HandSolder
R19, R20: 560; R_0603_1608Metric_Pad0.98x0.95mm_HandSolder
SW1: SW_Push; SW_Push_1P1T_NO_6x6mm_H9.5mm
TP1: Term En V TP; PinHeader_1x01_P2.54mm_Vertical
TP2: Econet TP header; PinHeader_1x12_P2.54mm_Vertical
TP3: Conn_01x01_Female; PinHeader_1x01_P2.54mm_Vertical
TP4: Collision Mon TP; PinHeader_1x01_P2.54mm_Vertical
TP5: VDD TX TP; PinHeader_1x01_P2.54mm_Vertical
U1, U3: SN65HVD75; SO-8_5.3x6.2mm_P1.27mm
U2: LMV324; SO-14_5.3x10.2mm_P1.27mm
U4: Upduino 3.1; DIP48_0.7in
U5: pololu_sd_breakout; pololu_sd_card

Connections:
+3.3V: C1.1, C9.1, J3.1, J5.16, J6.10, R12.1, R17.1, R18.1, TP2.1, U2.10 (+), U3.8 (Vcc), U4.9 (3v3), U5.2 (Vdd), U5.10 (Vdd)
+5V: C6.1, U2.4 (V+), U4.8 (5v)
/CLK+: J1.5 (CLK+), J2.5 (CLK+), JP2.1 (A), U3.6 (A)
/CLK-: J1.3 (CLK-), J2.3 (CLK-), JP1.1 (A), U3.7 (B)
/COLLISION_DETECT: Q5.3 (D), R18.2, TP2.2, U4.15 (GPIO32)
/COLLISION_DETECT_5V: Q5.1 (G), U2.7
/COLLISION_MON: R15.2, R16.1, TP4.1, U2.5 (+)
/COLLISION_REF_PWM: R2.1, R11.1, TP2.4, U4.17 (GPIO31)
/COL_LVL: R14.2, R15.1, U2.8
/DATA+: J1.1 (D+), J2.4 (D-), JP4.1 (A), U1.6 (A)
/DATA-: J1.4 (D-), J2.1 (D+), JP3.1 (A), U1.7 (B)
/ECONET_CLKEN: R1.1, R19.1, TP2.10, U3.2 (/RE), U3.3 (DE), U4.23 (GPIO38)
/ECONET_CLKIO: TP2.6, U3.1 (R), U3.4 (D), U4.19 (GPIO34_G0)
/ECONET_RXD: TP2.7, U1.1 (R), U4.20 (GPIO43)
/ECONET_TXD: TP2.8, U1.4 (D), U4.21 (GPIO36)
/ECONET_TXEN: TP2.9, U1.3 (DE), U4.22 (GPIO42)
/FLASH_SS: J6.9, U4.48 (GPIO16_SS0)
/GPIO_20: J5.15, U4.44 (GPIO20_G3)
/MISO: J6.6, U4.45 (GPIO17_MISO), U5.4 (DO)
/MOSI: J6.7, U4.46 (GPIO14_MOSI), U5.3 (DI)
/SCK: J6.8, U4.47 (GPIO15_SCK), U5.5 (SCLK)
/SD_CD: J6.2, R17.2, U4.38 (GPIO13), U5.7 (CD)
/SD_SS: J6.5, U4.43 (GPIO10_SS1), U5.6 (/CS)
/SS2: J6.4, U4.40 (GPIO12_SS2)
/SS3: J6.3, U4.39 (GPIO21_SS3)
/TERM_CLK+: JP2.2 (B), R10.1
/TERM_CLK-: JP1.2 (B), R7.2
/TERM_DATA+: JP4.2 (B), R8.2
/TERM_DATA-: JP3.2 (B), R9.2
/TERM_EN: D1.2, D2.1, R3.1, R20.1, TP2.3, U4.16 (GPIO35)
/TERM_EN_9V: C7.1, D3.2, Q1.1 (G), Q2.1 (G), Q3.1 (G), Q4.1 (G), R6.1, TP1.1
/TERM_HI: Q2.2 (S), U2.13 (-), U2.14
/TERM_LO: Q1.2 (S), U2.1, U2.2 (-)
/VDD_TX: C2.2, R12.2, R13.1, TP5.1, U1.8 (Vcc)
/V_1V4: R4.2, R5.1, U2.3 (+)
/V_1V8: R3.2, R4.1, U2.12 (+)
GND: C1.2, C2.1, C5.2, C6.2, C7.2, C8.2, C9.2, D5.1 (K), D6.1 (K), J1.2 (COM), J2.2 (COM), J3.9, J4.1, J5.1, J6.1, Q5.2 (S), R1.2, R5.2, R6.2, R16.2, SW1.1, TP2.12, U1.2 (/RE), U1.5 (GND), U2.11 (V-), U3.5 (GND), U4.1 (GND), U4.10 (GND), U4.42 (GND), U5.1 (GND), U5.11 (GND)
unnamed: C3.1, C4.1, D1.3, R2.2
unnamed: C3.2, D3.3
unnamed: C4.2, D2.3
unnamed: C5.1, D2.2, D3.1
unnamed: C8.1, R11.2, U2.6 (-)
unnamed: D5.2 (A), R19.2
unnamed: D6.2 (A), R20.2
unnamed: J3.2, U4.2 (VIO)
unnamed: J3.3, U4.4 (CDONE)
unnamed: J3.4, U4.5 (GPIO41_RGB2)
unnamed: J3.5, U4.6 (GPIO39_RGB0)
unnamed: J3.6, U4.7 (GPIO40_RGB1)
unnamed: J3.7, U4.11 (GPIO23)
unnamed: J3.8, U4.12 (GPIO25)
unnamed: J4.4, U4.13 (GPIO26_UART_RX)
unnamed: J4.5, U4.14 (GPIO27_UART_TX)
unnamed: J5.2, U4.25 (GPIO2)
unnamed: J5.3, U4.26 (GPIO46)
unnamed: J5.4, U4.27 (GPIO47)
unnamed: J5.5, U4.28 (GPIO45)
unnamed: J5.6, U4.29 (GPIO48)
unnamed: J5.7, U4.30 (GPIO3)
unnamed: J5.8, U4.31 (GPIO4)
unnamed: J5.9, U4.32 (GPIO44_G6)
unnamed: J5.10, U4.33 (GPIO6)
unnamed: J5.11, U4.34 (GPIO9)
unnamed: J5.12, U4.35 (GPIO11)
unnamed: J5.13, U4.36 (GPIO18)
unnamed: J5.14, U4.37 (GPIO19)
unnamed: Q1.3 (D), R9.1
unnamed: Q2.3 (D), R8.1
unnamed: Q3.2 (S), Q4.2 (S)
unnamed: Q3.3 (D), R7.1
unnamed: Q4.3 (D), R10.2
unnamed: R13.2, R14.1, U2.9 (-)
unnamed: SW1.2, U4.3 (RESET)
unnamed: TP2.5, U4.18 (GPIO37_G1)
unnamed: TP2.11, U4.24 (GPIO28)
unnamed: TP3.1, U4.41 (CLK_12MHz)

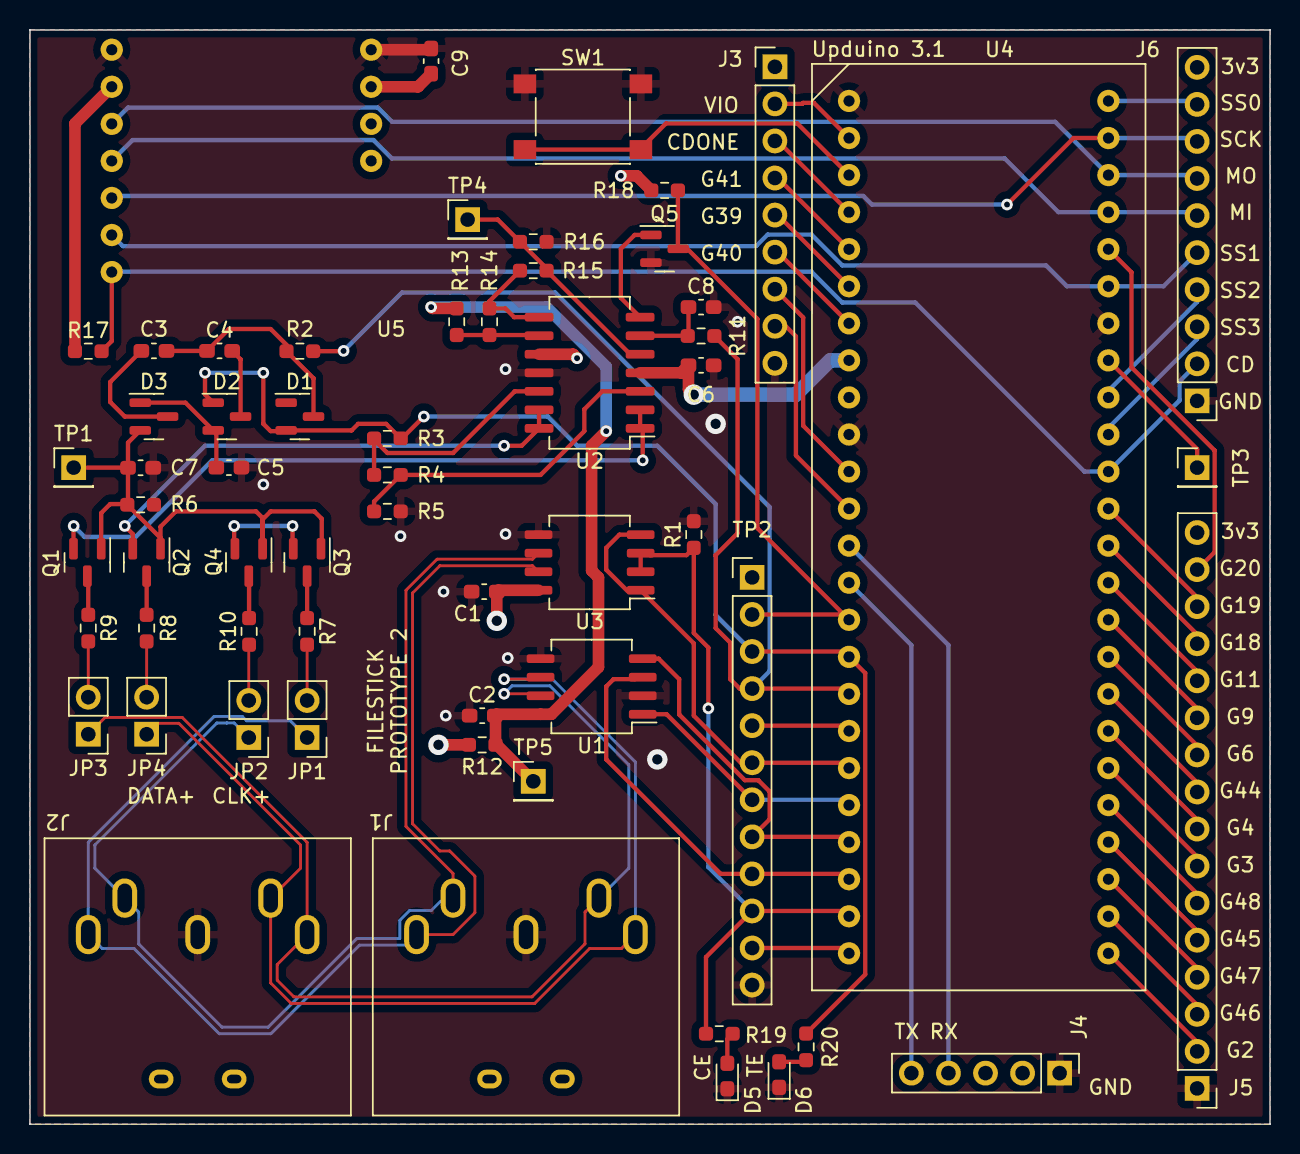
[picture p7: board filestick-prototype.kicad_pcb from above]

Board: 4 copper layers, 85.0 x 75.0 mm, 60 parts (0 on the bottom side), 76 nets.

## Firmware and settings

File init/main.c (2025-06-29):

/*
;The MIT License
;
;Copyright (c) 2025 Dylan Smith
;
;Permission is hereby granted, free of charge, to any person obtaining a copy
;of this software and associated documentation files (the "Software"), to deal
;in the Software without restriction, including without limitation the rights
;to use, copy, modify, merge, publish, distribute, sublicense, and/or sell
;copies of the Software, and to permit persons to whom the Software is
;furnished to do so, subject to the following conditions:
;
;The above copyright notice and this permission notice shall be included in
;all copies or substantial portions of the Software.
;
;THE SOFTWARE IS PROVIDED "AS IS", WITHOUT WARRANTY OF ANY KIND, EXPRESS OR
;IMPLIED, INCLUDING BUT NOT LIMITED TO THE WARRANTIES OF MERCHANTABILITY,
;FITNESS FOR A PARTICULAR PURPOSE AND NONINFRINGEMENT. IN NO EVENT SHALL THE
;AUTHORS OR COPYRIGHT HOLDERS BE LIABLE FOR ANY CLAIM, DAMAGES OR OTHER
;LIABILITY, WHETHER IN AN ACTION OF CONTRACT, TORT OR OTHERWISE, ARISING FROM,
;OUT OF OR IN CONNECTION WITH THE SOFTWARE OR THE USE OR OTHER DEALINGS IN
;THE SOFTWARE.
*/

#include <stdio.h>
#include <stdlib.h>
#include <stdint.h>
#include <sys/econet.h>
#include <sys/ioctl.h>
#include <sys/dirent.h>
#include <fcntl.h>
#include <unistd.h>
#include <errno.h>
#include <string.h>

#include <sys/mount.h>

#include "init.h"

// ----------------------------------------------------------------------
// On startup, argv[1] if present indicates whether this is a cold
// or warm start, or potentially any other useful information.
int
main(int argc, char **argv)
{
   if(argc > 1) {
      if(!strcmp(argv[1], "cold")) {
         printf("Cold boot, initializing flash file system\n");
         int rc = mount("flash", "", "fatfs", 0, NULL);
         if(rc < 0) {
            int e = errno;
            perror("mount");
            printf("errno = %d\n", e);
         }
      }
   }

   // Run CLI on stdin
   cli(0);
   return 0;
}

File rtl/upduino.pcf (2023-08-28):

# The LED pins are on dedicated pins and cannot be modified!
# Note that they are negative logic (write a 0 to turn on).
# These are also brought out to the left side of the board. 
# Cut the board trace on jumper R28 to disable the onboard 3 color LED.
set_io -nowarn led_green 39
set_io -nowarn led_red	41
set_io -nowarn led_blue	40

# FTDI chip interface
set_io -nowarn serial_txd 14 # FPGA transmit to USB
set_io -nowarn serial_rxd 15 # FPGA receive from USB
set_io -nowarn spi_cs 16 # Connected to SPI flash, drive high unless using SPI flash!
#set_io -nowarn spi_cs  12  # external CS

# If using the FTDI MPSSE engine, the following signals apply
set_io -nowarn spi_sck 15  # Shared with the flash
set_io -nowarn spi_ssn 16  # Connected to SPI flash, drive high unless using SPI flash!
#set_io -nowarn spi_mosi 17 # Shared with the flash
#set_io -nowarn spi_miso 14 # Shared with the flash
set_io flash_mosi 14
set_io flash_miso 17

# Normal GPIO pins, left side
set_io -nowarn uart_tx 23
set_io -nowarn uart_rx 25
set_io -nowarn econet_clk 26
set_io -nowarn econet_rx 27
set_io -nowarn econet_tx_p 32
set_io -nowarn econet_tx_n 35
set_io -nowarn econet_tx_enable 31
set_io -nowarn econet_receiving 37
set_io -nowarn gpio_34 34
set_io -nowarn gpio_43 43
set_io -nowarn gpio_36 36
set_io -nowarn gpio_42 42
set_io -nowarn gpio_38 38
set_io -nowarn gpio_28 28

# Normal GPIO pins, right side

# Following pins are added on the v3.0 of the board.
# SPI pins are brought out to the right side of the board

# Note: On board 12MHz clock can be brought to IOB_25B_G3 (pin 20) which is a global
# clock input. Short across R16 (labelled OSC on the board) to enable 12MHz clock to
# pin 20.
set_io -nowarn input_clk 20
set_io -nowarn gpio_10 10

# Following are also found on v2.x of the UPduino
set_io -nowarn gpio_12 12
set_io -nowarn gpio_21 21
set_io -nowarn gpio_13 13
set_io -nowarn gpio_19 19
set_io -nowarn gpio_18 18
set_io -nowarn gpio_11 11
set_io -nowarn gpio_9 9
set_io -nowarn gpio_6 6
set_io -nowarn gpio_44 44
set_io -nowarn gpio_4 4
set_io -nowarn gpio_3 3
set_io -nowarn gpio_48 48
set_io -nowarn gpio_45 45
set_io -nowarn gpio_47 47
set_io -nowarn gpio_46 46
set_io -nowarn gpio_2 2

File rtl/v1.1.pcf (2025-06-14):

# Main 12MHz clock
set_io -nowarn input_clk   20    # G3

# RGB LED
set_io -nowarn led_green   39
set_io -nowarn led_red	   41
set_io -nowarn led_blue	   40

# dedicated SPI port for the flash memory
set_io -nowarn spi_ss[0]   16   # Connected to SPI flash, drive high unless using SPI flash!
set_io -nowarn flash_sck   15   # Shared with the flash
set_io flash_mosi          14   # when FPGA is master
set_io flash_miso          17   # when FPGA is master

# UART
set_io -nowarn uart_rx     38 
set_io -nowarn uart_tx     37

# Econet
set_io -nowarn term_en           12
set_io -nowarn collision_ref_pwm 13
set_io -nowarn collision_detect  18
set_io -nowarn econet_clkio      44    # G6
set_io -nowarn econet_rx         11
set_io -nowarn econet_tx         9
set_io -nowarn econet_tx_enable  10
set_io -nowarn econet_clken      6
set_io -nowarn econet_receiving  19

# SPI port/SD card
set_io -nowarn spi_ss[1]         2     # SD card
set_io -nowarn spi_ss[2]         3
set_io -nowarn spi_ss[3]         4
set_io -nowarn spi_sck           47    # to SDcard and SPI connector
set_io -nowarn spi_mosi          48
set_io -nowarn spi_miso          46
set_io -nowarn sd_present        45

# Add normal GPIO pins below

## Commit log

2023-07-17 Add rgb led device, ensure allocation flag is set
2023-07-22 Add disable/enable interrupts macro
2023-07-31 Use standard syscalls for SPI flash
2023-08-20 Fix widths in buffered econet
    [econet_rx_buffered.v]
2023-09-03 Econet receiver hardware does more frame decoding
2023-09-12 turn on econet rx interrupt
2023-09-16 Reset uart ready status on read byte not read status
2023-09-16 Fix console buffer addresses
    [console.c]
2023-09-16 Simplify the frame-ready reset
    [econet_rx_buffered.v]
2023-09-16 Add a timer
2023-09-17 timer should only fire interrupt when enabled
2023-09-18 add rx data frame timeout
2023-09-20 implement delay for non-turnaround frames
2023-11-26 new spi core
2023-11-27 Add new spi core to top level
2023-11-28 Fix bugs in the SPI core
2023-11-29 More SPI fixes
2023-12-02 SPI test code
2023-12-03 Boot and run with new SPI core
2023-12-05 Generic SPI write routine
2023-12-06 Generic SPI read
2023-12-23 Add interrupt register bank
2023-12-23 Use interrupt register bank
2023-12-24 add SD card switch detect plus a PLL system clock timing option
2024-01-14 add printk, file read/write
2024-01-16 use printk
2024-03-16 add prototype kicad project
    [filestick-prototype.kicad_pcb, filestick-prototype.kicad_sch]
2024-03-16 fix clk pins
    [filestick-prototype.kicad_sch]
2024-03-17 add termination circuit
    [filestick-prototype.kicad_sch]
2024-03-17 schematic save
    [filestick-prototype.kicad_sch]
2024-03-22 Add symbol for SD card breakout board
    [filestick-prototype.kicad_sch]
2024-03-22 more schematic
    [filestick-prototype.kicad_sch]
2024-03-25 add GPIO headers etc
    [filestick-prototype.kicad_sch]
2024-03-25 add annotations and footprints
    [filestick-prototype.kicad_sch]
2024-03-25 More footprints
    [filestick-prototype.kicad_sch]
2024-03-26 add capacitor to SD card IF
    [filestick-prototype.kicad_sch]
2024-03-29 PCB and footprints
    [filestick-prototype.kicad_pcb, filestick-prototype.kicad_sch]
2024-03-31 clamp collision detection at 3v3, add leds etc
    [filestick-prototype.kicad_pcb, filestick-prototype.kicad_sch]
2024-04-01 better level shifter
    [filestick-prototype.kicad_pcb, filestick-prototype.kicad_sch]
2024-04-01 Some unsaved stuff
    [filestick-prototype.kicad_sch]
2024-04-01 update top level and PCF for prototype board
2024-04-01 add prototype gerbers
    [filestick-prototype-B_Cu.gbr, filestick-prototype-B_Mask.gbr, filestick-prototype-Edge_Cuts.gbr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]
2024-04-14 fix prototype PCB errors
    [filestick-prototype.kicad_pcb, filestick-prototype.kicad_sch]
2024-04-24 add synchronizer to prevent metastable state in interrupt line
    [econet_rx_buffered.v]
2024-04-24 eliminate some LED usage, fiddle with CD PWM
2024-04-24 revert change to pwm
2024-04-24 add collision detect to PCF
    [upduino2.pcf]
2024-04-24 cleanup uart input
2024-04-27 make SPI flash a dedicated SPI port
2024-04-29 Update schematic with dedicated flash spi port
    [filestick-prototype.kicad_sch]
2024-07-27 Start on final board
    [filestick.kicad_pcb, filestick.kicad_sch]
2024-09-17 Mainly add SD card to schematic
    [filestick.kicad_sch]
2025-01-11 Finish schematic connections
    [filestick.kicad_sch]
2025-01-12 Add footprints to schematic
    [filestick.kicad_sch]
2025-01-18 Distribute components on the PCB
    [filestick.kicad_pcb, filestick.kicad_sch]
2025-01-19 Fix econet socket on schematic and route econet front end
    [filestick.kicad_pcb, filestick.kicad_sch]
2025-01-21 Improve fpga pin assignments
    [filestick.kicad_pcb, filestick.kicad_sch]
2025-01-25 Add v1 pcb pin file
2025-01-25 Move uart TX/RX
2025-01-25 Route the rest of the PCB
    [filestick.kicad_pcb, filestick.kicad_sch]
2025-06-04 fix UART pin designations
2025-06-10 Update kicad files to v9, turn micro-sd card slot the right way
    [filestick.kicad_pcb, filestick.kicad_sch]
2025-06-28 Add raw mode to the console driver
2025-06-28 sadly, we have to go to 115200 baud due to problems with the UART
    [console.c]
2025-06-29 Fix broken bits in the CLI
    [main.c]
2025-07-05 Add a hardware fifo to the UART
2025-07-13 improve onboard spi flash access
2025-07-26 Add USB power soft start, CTS and RTS
    [filestick.kicad_sch]
2025-12-23 Stop the UART tx from prematurely signalling it's ready
2026-10-28 Add a C emulator for the FileStick system
    Emulates the modified FemtoRV32 core with cycle timing from its state
    machine, SPRAM and block RAM boot ROM, the UART on a Linux pty, the SPI
    controller with an AT25SF081 compatible flash (CS 0) and an SDHC card
    (CS 1) backed by files, the GP timer, econet timer A and SD card detect.
    The econet interface is a stub. Runs at 10MHz in 1ms time slices.
2026-10-28 Fix interrupt versus trap bugs where an interrupt could cause traps to be lost.
2026-10-28 Give traps priority over interrupts in the emulator
    Match the RTL fix: a trap (ecall, ebreak, illegal instruction or
    privilege violation) is taken in preference to an interrupt on the same
    instruction, and the interrupt no longer sets M mode. An interrupt is
    also held off on a load or store that causes a privilege violation, so
    the violation trap is taken on the next instruction instead of being
    cleared by the ISR's M mode.
    Previously an ecall coinciding with an interrupt was skipped and left
    the user program running in S mode, and a violating access coinciding
    with an interrupt went untrapped.
    This also models m_set being gated by new_violation, which the RTL
    needs as well.
    Co-Authored-B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
2026-10-29 Add a BBC BASIC interpreter for the FileStick
    A BBC BASIC II compatible interpreter in C, about 28K of code for
    rv32imc, leaving about 33K free for programs. Programs use the BASIC II
    tokenised format (keyword table from the ROM), so BBC Micro programs
    LOAD directly; text files can be loaded too.
    Reals are BBC style 40 bit floats implemented in software, which is
    much smaller than libgcc's soft float doubles and gives the same
    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
2026-10-30 Add a gdb remote protocol server to the emulator
    -g PORT lets riscv-none-elf-gdb connect with "target remote" to set
    breakpoints and watchpoints, single step, interrupt the running system
    and read and write registers (both banks and the CSRs) and memory.
    Emulated time stops while gdb has the CPU stopped.
2026-11-01 Add a CPU test suite for the unprivileged RV32IMC instructions
    cputest.elf checks each RV32I, RV32M and RV32C instruction (except
    ecall/ebreak) against the RISC-V specification, plus the register file,
    far branch offsets and 32 bit instructions straddling a word boundary.
    The tests are in assembler so the exact encoding under test is used;
    the ALU and M expected values are generated by gen_alu.py from a
    reference model of the spec.
    FENCE is only tested with -f, since the core currently traps it as an
    illegal instruction. AUIPC fails for results above 24 bits, as the core
    only computes ADDR_WIDTH bits.
2026-11-03 Emulator: emulate econet over UDP in the style of BeebEm
    Replace the econet stub with an emulation of the receiver, transmitter
    and hardware control registers, networked the way BeebEm, b-em and
    aund's beebem mode do it: each econet frame is one UDP datagram, with
    stations mapped to IP addresses and ports by the usual econet.cfg file
    (-e FILE).
    The emulator binds the UDP port of the station the software programs
    into the receiver (or --econet-station). Frames are sent to every other
    station in the file, as aund does, and the receiver filters on address
    as the hardware does, so monitor mode works. Frames take time on the
    line at --econet-bitrate, with the receiving/busy status, the 15 bit
    id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
